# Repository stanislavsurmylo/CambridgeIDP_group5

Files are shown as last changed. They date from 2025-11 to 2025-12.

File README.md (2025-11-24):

# CambridgeIDP_group5

This repository contains our code and CAD models the Cambridge IB IDP group M205. 

# Team members 
1. Victor Liu
2. Luke Wiggins
3. Su Liu
4. Mykhailo (Misha) Lysakov
5. Arya Bhattacharya
6. Cerys Brown
7. Stanislav (Stas) Surmylo

## Team allocations
Mechanical: 
- Cerys Brown
- Luke Wiggins
- Arya Bhattacharya

Electrical:
- Victor Liu

Software: 
- Su Liu 
- Misha Lysakov
- Stas Surmylo

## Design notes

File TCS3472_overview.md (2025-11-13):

## TCS3472 Color Sensor Reader (I2C)

###
- TCS3472 RGB color and ambient light sensor
- Measures red, green, blue color values and light intensity
- I2C digital interface (3.3–5 V compatible)
- Onboard LED for illumination

### Wiring
- `SDA` ➜ GP4
- `SCL` ➜ GP5
- `VCC` ➜ 3V3 (or 5V)
- `GND` ➜ GND

### Notes
- Returns RGB tuple (red, green, blue) and light value
- I2C address: 0x29 (default)
- Readings update every 1 second (configurable)
- Requires driver: `libs/tcs3472_micropython/tcs3472.py`

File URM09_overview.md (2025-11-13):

## URM09 Analog Distance Tracker 

###
- URM09 Ultrasonic Distance Sensor (2–500 cm)
- Outputs an **analog voltage** that changes with distance
-  `distance_cm = (Vout(mV) × 520) / Vin(mV)`
- With 3.3 V supply: `distance_cm ≈ volts × 157.58`

### Wiring
- `AOUT` ➜ GP26 (ADC0)
- `VCC` ➜ 3V3
- `GND` ➜ GND

### Notes
- Analog readings can be noisy—average samples if needed
- NEED calibration!!!

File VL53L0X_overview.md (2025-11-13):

## VL53L0X ToF Distance Reader (I2C)

###
- VL53L0X Time-of-Flight sensor (30–2000 mm)
- Smart sensor with built-in laser timing and processing
- Communicates digitally over I2C (needs clock + data wires)

### Wiring
- `SDA` ➜ GP8
- `SCL` ➜ GP9
- `VCC` ➜ 3V3 (works 3.3–5 V)
- `GND` ➜ GND

### Notes
- I2C allows multiple devices on the same bus (address 0x29 default)
- Readings are 1 mm resolution, accuracy about ±3%
- Keep sensor still during init; avoid covering the aperture

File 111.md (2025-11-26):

# Loading Pipeline Overview

## Purpose
- Detect an object near the loader using the TMF8701 range sensor.
- Classify cube color with the TCS3472 only when needed to save power.
- Move the linear actuator to lift the object once distance and color checks pass.

## Hardware
- `TMF8701` time-of-flight sensor on I2C (`I2C_ID=0`, `PIN_SDA=8`, `PIN_SCL=9`).
- `TCS3472` color sensor, power-gated via `COLOR_POWER_PIN=0`.
- `Actuator` driven by direction pin `3` and PWM pin `2`.

## Configuration
- `LOADING_ZONE` selects actuator default positions (1: zone down, 2: zone up).
- Timing constants:
  - `INIT_RETRACT_TIME`: retract to bottom.
  - `ZONE_DOWN_EXTEND_TIME`: default extension for zone down.
  - `LIFT_TIME`: duration of lift once triggered.
- `REFERENCE_DISTANCE_CM` determines trigger distance (default 3 cm).

## Execution Flow
1. **Sensor Setup**  
   `setup_sensor()` initializes TMF8701 and starts distance measurement mode.
2. **Actuator Initialization**  
   `initialize_actuator()` retracts fully, then extends according to `LOADING_ZONE`.
3. **Main Loop** (`main()`):
   - Continuously reads distance via `read_distance_cm()`.
   - When distance ≤ `REFERENCE_DISTANCE_CM`, powers the TCS3472, samples light/RGB, and detects color.
   - If not previously triggered, extends actuator at `ACTUATOR_SPEED` for `LIFT_TIME` seconds, then stops.
   - Resets trigger when distance goes above `REFERENCE_DISTANCE_CM + 1`.

## Color Detection
- `detect_color()` derives normalized RGB ratios.
- Tags `RED`, `GREEN`, `BLUE`, `YELLOW`, or `DARK` / `UNKNOWN` based on thresholds.

## Operation Notes
- Loop delay is `0.2 s`, balancing responsiveness with sensor stability.
- TMF8701 measurement calls use `start()/read()/stop()` for each sample to ensure fresh data.
- Color sensor is only powered when an object is close, reducing noise and power.

## Troubleshooting
- Initialization failures raise explicit `RuntimeError` messages for quick diagnosis.
- Ensure I2C wiring matches configured pins; desktop lint warnings about `machine`/`utime` are expected on non-MicroPython hosts.

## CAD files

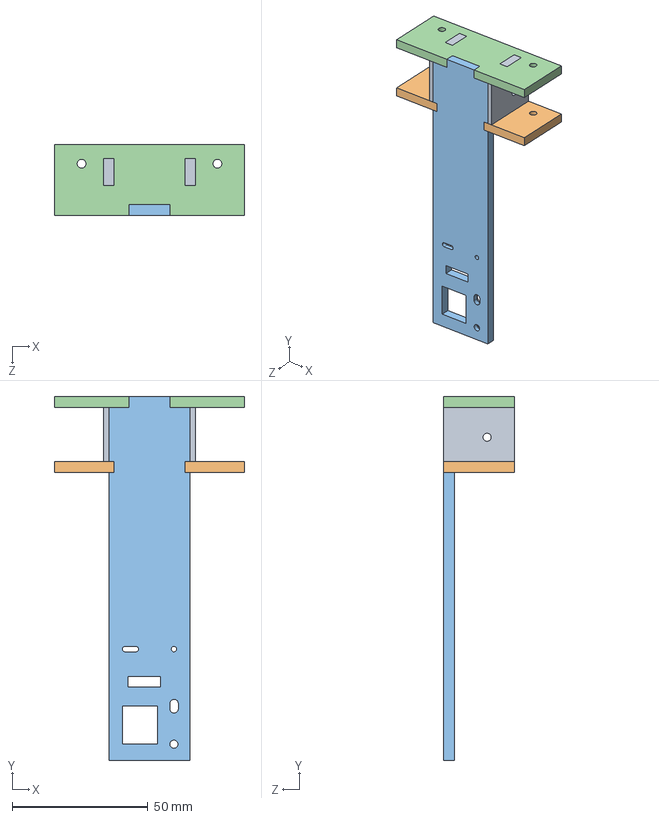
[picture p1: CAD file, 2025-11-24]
3d_models/Forklift/forklift.SLDASM
70.0 x 134.0 x 26.0 mm
forklift_baseplate
forklift_front_face
forklift_upper_notch x 2
forklift_vertical_edge x 2

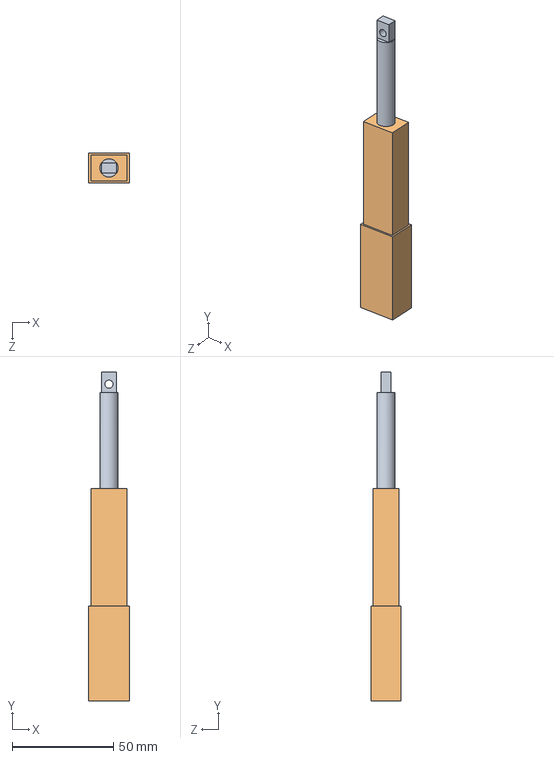
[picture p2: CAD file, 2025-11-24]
3d_models/actuator.SLDASM
20.0 x 162.4 x 15.0 mm
actuator_base
actuator_mover

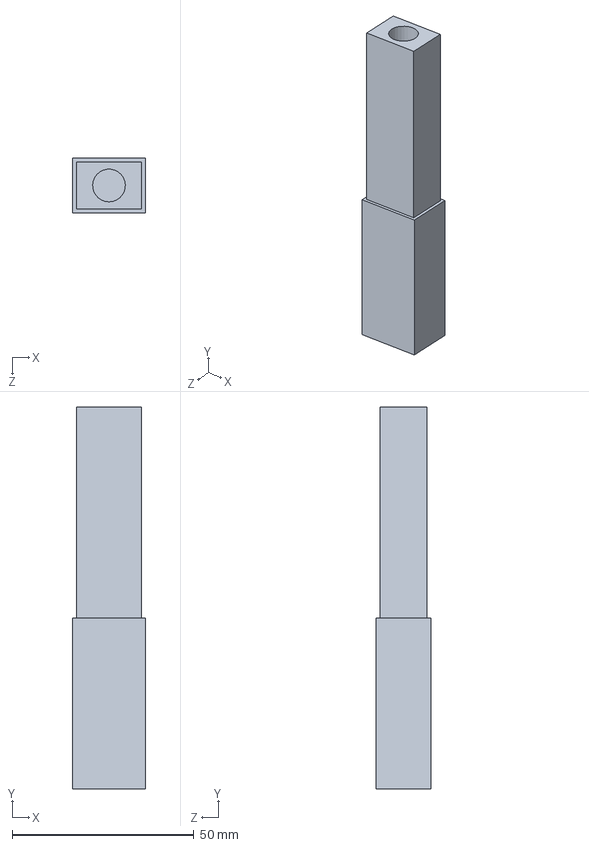
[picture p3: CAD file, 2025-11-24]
3d_models/actuator_base.SLDPRT
20.0 x 105.0 x 15.0 mm

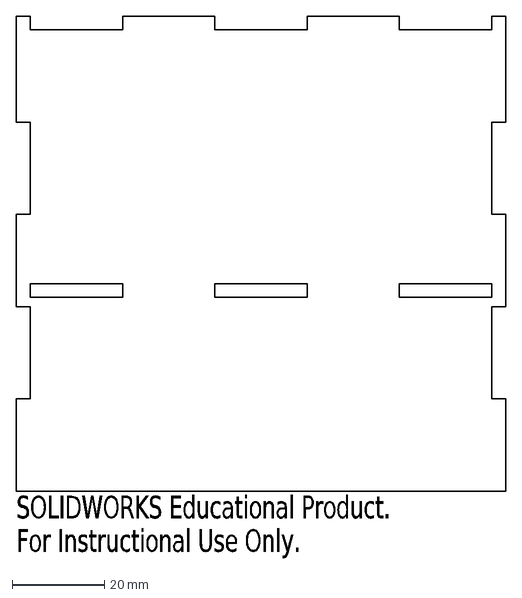
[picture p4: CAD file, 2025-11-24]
3d_models/laser cutting files/back.DXF
SOLIDWORKS Educational Product.
For Instructional Use Only.

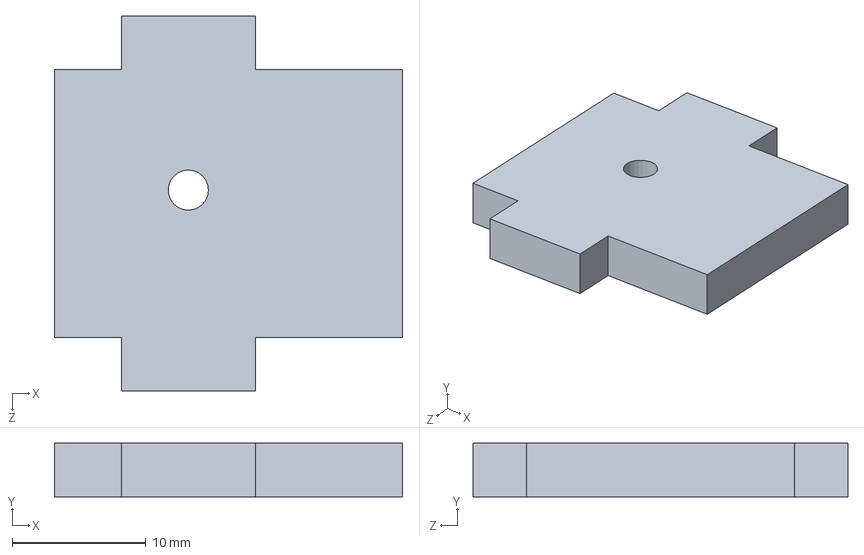
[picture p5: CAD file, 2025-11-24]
3d_models/Forklift/forklift_vertical_edge.SLDPRT
26.0 x 4.00 x 28.0 mm

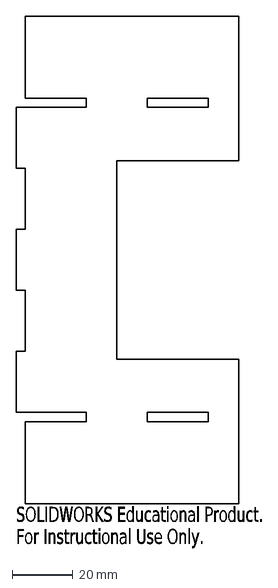
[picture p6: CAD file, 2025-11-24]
3d_models/laser cutting files/above_wheel.DXF
SOLIDWORKS Educational Product.
For Instructional Use Only.

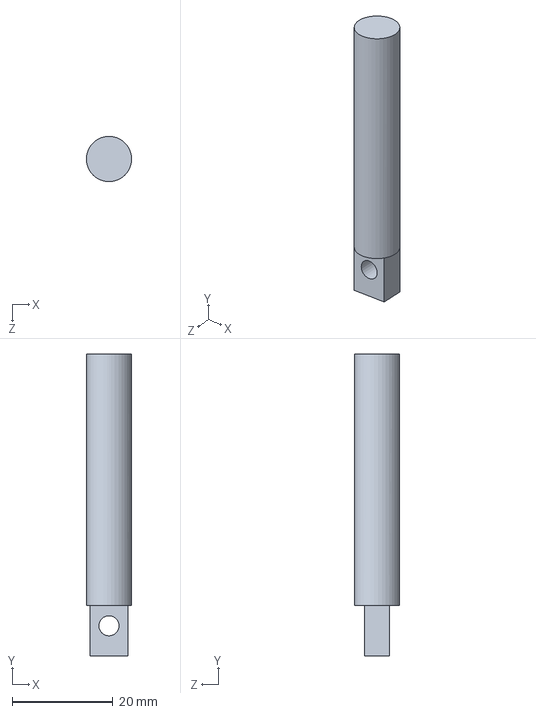
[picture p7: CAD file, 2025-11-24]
3d_models/actuator_mover.SLDPRT
8.99 x 60.0 x 9.00 mm

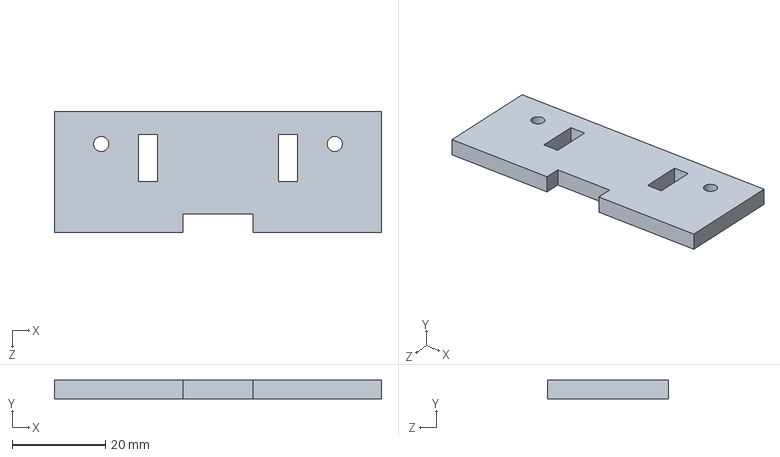
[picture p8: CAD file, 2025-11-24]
3d_models/Forklift/forklift_baseplate.SLDPRT
70.0 x 4.00 x 26.0 mm

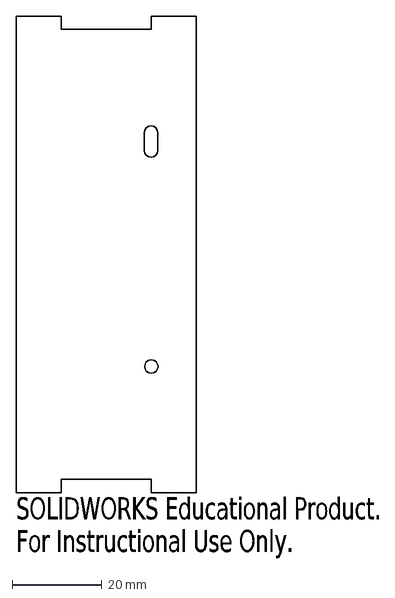
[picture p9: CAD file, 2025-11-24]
3d_models/laser cutting files/top.DXF
SOLIDWORKS Educational Product.
For Instructional Use Only.

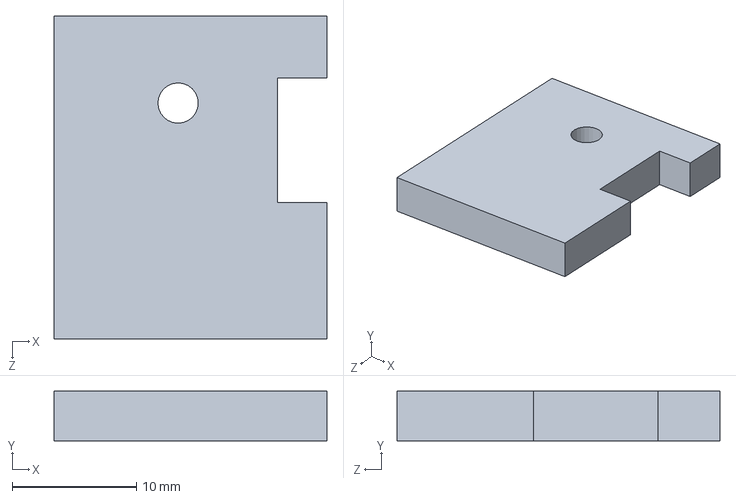
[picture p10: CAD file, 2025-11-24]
3d_models/Forklift/forklift_upper_notch.SLDPRT
22.0 x 4.00 x 26.0 mm

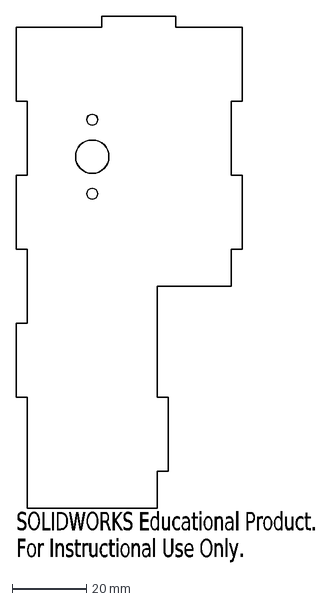
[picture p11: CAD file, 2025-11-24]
3d_models/laser cutting files/side.DXF
SOLIDWORKS Educational Product.
For Instructional Use Only.

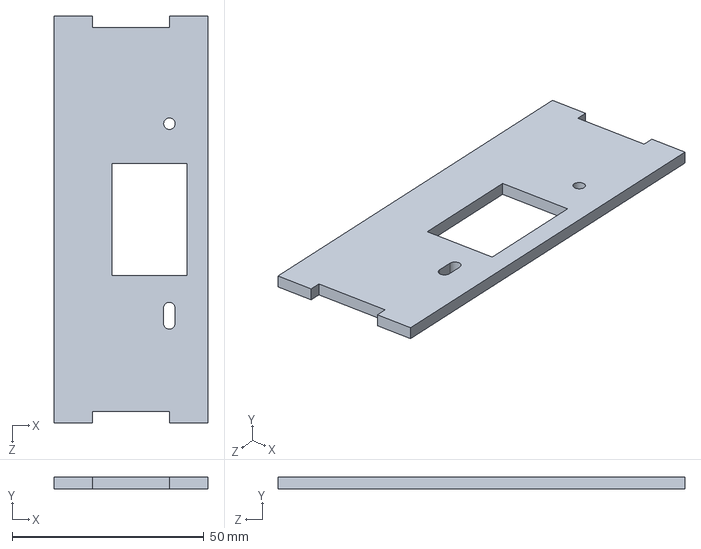
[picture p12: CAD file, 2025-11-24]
3d_models/top.SLDPRT
40.0 x 3.00 x 106.0 mm

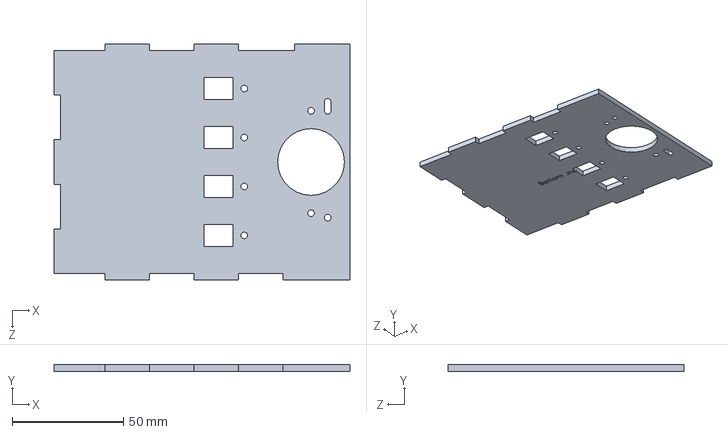
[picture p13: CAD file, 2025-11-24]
3d_models/bottom.SLDPRT
133.0 x 3.00 x 106.0 mm

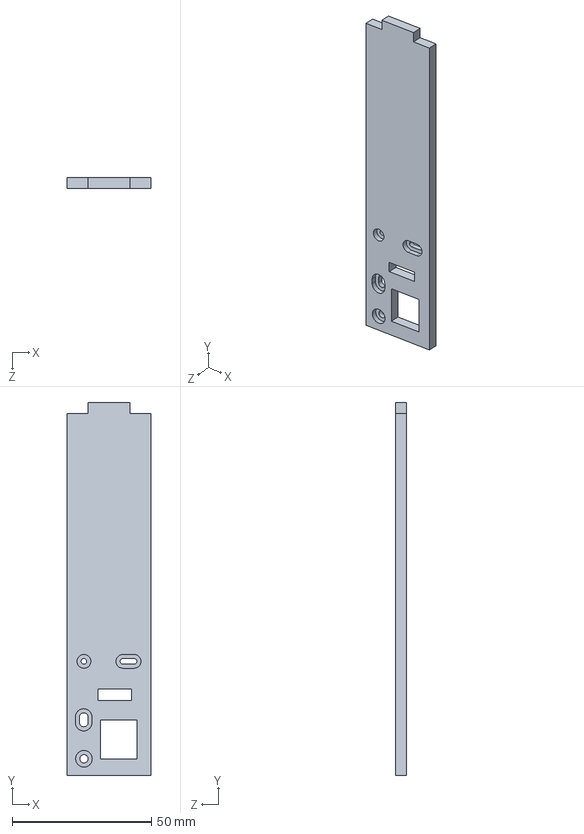
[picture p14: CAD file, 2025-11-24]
3d_models/Forklift/forklift_front_face.SLDPRT
30.0 x 134.0 x 4.00 mm

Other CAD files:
3d_models/box_assembly.SLDASM
3d_models/ballbearing_and_mount.SLDASM
3d_models/laser cutting files/bottom.DXF
3d_models/back.SLDPRT
3d_models/Forklift/forklift.SLDPRT
3d_models/Forklift/forklift.STL
3d_models/above_wheel.SLDPRT
3d_models/ballbearing mount.SLDPRT
3d_models/ballbearing.SLDPRT
3d_models/battery.SLDPRT
3d_models/pico.SLDPRT
3d_models/side.SLDPRT
3d_models/wheel.SLDPRT

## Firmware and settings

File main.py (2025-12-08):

# four_sensor_table_arc.py — 4-bit follower + debounced arc turns
import loading_pipeline_state_machine
# Core line-following and loading logic for the robot. Additive comments only;
# functional code remains unchanged.
from machine import Pin, PWM, I2C
from time import sleep_ms, ticks_ms, ticks_diff, sleep
import rp2
import map
from map import V
import vl53l0x_distance
from vl53l0x_distance import setup_sensor_vl53l0x, vl53l0x_read_distance
from libs.tmf8701 import DFRobot_TMF8701
from linear_actuator import Actuator
import loading_pipeline
from loading_pipeline import loading_pipeline_main
from loading_pipeline_state_machine import LoadingPipelineState, pipeline_step

PIN_YELLOW = 17
BUTTON_PIN = 14 
 # zone down = 1, zone up = 2

# I2C pins shared with TMF8701
I2C_ID = 0
PIN_SDA = 8
PIN_SCL = 9

# I2C pins for TCS3472
I2C_ID_TCS3472 = 1
PIN_SDA_TCS3472 = 10
PIN_SCL_TCS3472 = 11

# TCS3472 power control
COLOR_POWER_PIN = 0
COLOR_POWER_STABILIZE_MS = 200
COLOR_INTEGRATION_MS = 500
# Above constants group hardware pin definitions and timing knobs. Values tuned
# on physical hardware, so untouched for correctness.

# Actuator pins
ACTUATOR_DIR_PIN = 3
ACTUATOR_PWM_PIN = 2

# Timing constants
INIT_RETRACT_TIME = 6.0  # Retract to bottommost position
ZONE_DOWN_EXTEND_TIME = 3.0  # Extend to default position for zone_down
ZONE_UP_EXTEND_TIME = 0  # Extend to default position for zone_up
LIFT_TIME = 3.0  # Base lift time when starting loading
ACTUATOR_SPEED = 70

MIN_INIT_DISTANCE_CM = 5
ZONE_PRESET_DISTANCE_CM = 10.0 # Trigger zone preset extend
COLOR_REFERENCE_DISTANCE_CM = 5  # Trigger color sampling
LIFT_REFERENCE_DISTANCE_CM = 3  # Trigger lift phase
LOOP_DELAY = 0.2


# ----- TUNING -----
BASE  = 80    # straight speed
SPIN_BASE = 50
LOAD_BASE = 40
SEEK_COEFF = 0.5  # how aggressively to seek line
DELTA = 20*(BASE/60)    # small correction to reach 0110
HARD  = 40*(BASE/60)    # strong correction when far(turns)
TURN_OUT = 100 # arc outer wheel speed
TURN_IN  = 0 # arc inner wheel speed
DEBOUNCE = 3  # front trigger must persist N cycles
STABLE   = 1  # need N centered readings to finish a turn
MAX_TURN_MS = 10                                                 
  
COLOUR_DETECTION_DISTANCE = 50  # distance to detect color in mm
PICKUP_DISTANCE = 40.0  # distance to pick up box in mm

DT_MS = 5


RADIUS_OF_TURN = 16.5  # radius of turn in cm

    # Radius of turn = 16.5 cm
    # Angle is 90 degrees
    # turn distance is (π * 16.5) / 2 = 25.9 cm
    # Speed is 15 cm/F at power 60
    #  At power 100, speed is 25 cm/F
    # Time to turn 25.9 cm at 25 cm/F = 1.036 F



@rp2.asm_pio(set_init=rp2.PIO.OUT_LOW)
def blink_1hz():
    set(pins, 1)           # LED ON
    set(x, 31)             [6]
    label("delay_high")
    nop()                  [29]
    jmp(x_dec, "delay_high")

    set(pins, 0)           # LED OFF
    set(x, 31)             [6]
    label("delay_low")
    nop()                  [29]
    jmp(x_dec, "delay_low")

# def unload_robot():
#     go(0,0)
#     # Unloading robot to reduce weight on actuator
#     actuator = Actuator(ACTUATOR_DIR_PIN, ACTUATOR_PWM_PIN)
    
#     # Test retract
#     actuator.retract(speed=100)
#     sleep(1)
#     actuator.stop()
#     sleep(1)  # Pause so you can measure
#     print("Unloading complete")

# Global flags for button control
robot_started = False  # True after first button press (start)
emergency_stop = False  # True when paused (after robot has started)
global_actuator = None  # Global actuator reference for emergency stop

def _button_irq(pin):
    global robot_started, emergency_stop, global_actuator
    # Toggle run/pause states on button press; stop all motion when pausing.
    if not robot_started:
        robot_started = True
        emergency_stop = False
    else:
        emergency_stop = not emergency_stop
        if emergency_stop:
            mL.stop()
            mR.stop()
            # Stop actuator if it exists
            if global_actuator is not None:
                try:
                    global_actuator.stop()
                except:
                    pass

# Trigger on falling edge (button pressed to GND when using pull-up)
button = Pin(BUTTON_PIN, Pin.IN, Pin.PULL_UP)
button.irq(trigger=Pin.IRQ_FALLING, handler=_button_irq)

#vl53l0x distance sensor:
setup_sensor1 = setup_sensor_vl53l0x()

# colour sensor:
color_power = Pin(COLOR_POWER_PIN, Pin.OUT, value=0)

# Global variable to store initialized sensor (singleton pattern)
_setup_sensor2 = None

def actuator_slope_up():
    actuator = Actuator(ACTUATOR_DIR_PIN, ACTUATOR_PWM_PIN)
    actuator.extend(speed=100)
    sleep(0.1)
    actuator.stop()
    sleep(0.1)
    print("Actuator slope up complete")

def actuator_slope_down():
    actuator = Actuator(ACTUATOR_DIR_PIN, ACTUATOR_PWM_PIN)
    actuator.retract(speed=100)
    sleep(0.1)
    actuator.stop()
    sleep(0.1)
    print("Actuator slope down complete")

def setup_sensor_tmf8701():
    global _setup_sensor2
    # Return existing sensor if already initialized
    if _setup_sensor2 is not None:
        return _setup_sensor2
    
    try:
        i2c = I2C(I2C_ID, sda=Pin(PIN_SDA), scl=Pin(PIN_SCL))
        sensor = DFRobot_TMF8701(i2c)
        if sensor.begin() != 0:
            raise RuntimeError("TMF8701 initialization failed")
        if not sensor.start_measurement(sensor.eMODE_NO_CALIB, sensor.eCOMBINE):
            raise RuntimeError("TMF8701 failed to start measurement")
        print("TMF8701 distance reader ready.")
        _setup_sensor2 = sensor  # Store for reuse
        return sensor
    except OSError as e:
        print(f"I2C error in setup_sensor_tmf8701: {e}")
        raise
    except Exception as e:
        print(f"Error in setup_sensor_tmf8701: {e}")
        raise

def read_distance_mm(sensor):
    try:
        if sensor.is_data_ready():
            dist_mm = sensor.get_distance_mm()
            return dist_mm
    except Exception as e:
        # Handle I2C timeout or other communication errors
        print(f"I2C error in read_distance_mm: {e}")
        return None
    return None

# Global variables for sensor and loading state (initialized in main())
setup_sensor2 = None
loading_state = None


# ----- SENSORS (left->right). Swap sFL,sFR wires here if needed -----
S_FL = Pin(19, Pin.IN)   # front-left  (outer)
S_BL = Pin(21, Pin.IN)   # back-left   (inner)
S_BR = Pin(18, Pin.IN)   # back-right  (inner)
S_FR = Pin(20, Pin.IN)   # front-right (outer)
WHITE_LEVEL = 1
def W(x): return x == WHITE_LEVEL


# branch_route = []  path = list of vertices; route = list of 'L','R','F','B'
# branch_index = 0
current_heading = 0
current_vertex = V.START
finish_vertex = None
finish_heading = None


# ----- MOTORS -----
INVERT_LEFT  = False     # flip these until forward() drives robot forward
INVERT_RIGHT = False



class Motor:   
    def __init__(self, d, p, inv=False):
        self.dir=Pin(d,Pin.OUT); self.pwm=PWM(Pin(p)); self.pwm.freq(1000); self.inv=inv
    def fwd(self, sp): self.dir.value(0 ^ self.inv); self.pwm.duty_u16(int(65535*max(0,min(100,int(sp)))/100))
    def bwd(self, sp): self.dir.value(1 ^ self.inv); self.pwm.duty_u16(int(65535*max(0,min(100,int(sp)))/100))
    def stop(self): self.pwm.duty_u16(0)

mL = Motor(4,5, INVERT_LEFT)
mR = Motor(7,6, INVERT_RIGHT)
# Simple motor wrapper: forward/back/stop with PWM duty capping; inversion flag
# lets wiring swaps keep logical directions consistent.


def read_code():
    # return 4-bit left->right
    b3 = 1 if W(S_FL.value()) else 0
    b2 = 1 if W(S_BL.value()) else 0
    b1 = 1 if W(S_BR.value()) else 0
    b0 = 1 if W(S_FR.value()) else 0
    return (b3<<3)|(b2<<2)|(b1<<1)|b0


def go(vL, vR): mL.fwd(vL); mR.fwd(vR)
def spin_left(): mL.bwd(SPIN_BASE); mR.fwd(SPIN_BASE)
def spin_right(): mL.fwd(SPIN_BASE); mR.bwd(SPIN_BASE)
def go_back(vL, vR): mL.bwd(vL); mR.bwd(vR)

def shift_with_correction(duration_ms):
    global emergency_stop
    # Drive forward for a fixed time while line-correcting unless paused.
    t0 = ticks_ms()
    while ticks_diff(ticks_ms(), t0) < duration_ms:
        if emergency_stop:
            go(0, 0)
            break
        c = read_code()

        if centered(c):
            go(BASE, BASE)
        elif slight_left(c):          # call the function
            go(BASE - DELTA, BASE + DELTA)
        elif slight_right(c):         # call the function
            go(BASE + DELTA, BASE - DELTA)
        elif c in (0b1100, 0b1000):   # far to left
            go(BASE - HARD, BASE + HARD)
        elif c in (0b0011, 0b0001):   # far to right
            go(BASE + HARD, BASE - HARD)
        else:
            # unknown/lost -> move forward
            go(BASE, BASE)

        sleep_ms(DT_MS)

def shift_back_without_correction(duration_ms):
    global emergency_stop
    # Reverse straight for a fixed duration; avoids line correction for speed.
    t0 = ticks_ms()
    while ticks_diff(ticks_ms(), t0) < duration_ms:
        if emergency_stop:
            go(0, 0)
            break
        go_back(BASE, BASE)
        # c = read_code()

        # if centered(c):
        #     go_back(BASE, BASE)
        # elif slight_left(c):          # call the function
        #     go_back(BASE - DELTA, BASE + DELTA)
        # elif slight_right(c):         # call the function
        #     go_back(BASE + DELTA, BASE - DELTA)
        # elif c in (0b1100, 0b1000):   # far to left
        #     go_back(BASE - HARD, BASE + HARD)
        # elif c in (0b0011, 0b0001):   # far to right
        #     go_back(BASE + HARD, BASE - HARD)

        sleep_ms(DT_MS)



def arc(side):
    global current_heading
    add_branch_index = 0
    # Execute a 90/180 degree arc turn or short forward hop based on route code.
    if side=='R':
        DEGREE_OF_TURN = 90
        add_branch_index += 1
        go(TURN_OUT, TURN_IN)   # inner slower
        turn_sleep(DEGREE_OF_TURN, (TURN_OUT - TURN_IN))
        print('R')

    elif side=='L':
        DEGREE_OF_TURN = 90     
        add_branch_index += 1
        go(TURN_IN, TURN_OUT)
        turn_sleep(DEGREE_OF_TURN, (TURN_OUT - TURN_IN))
        print('L')
    
    elif side == 'B': 
        DEGREE_OF_TURN = 180
        add_branch_index += 1
        go(TURN_IN, TURN_OUT)
        turn_sleep(DEGREE_OF_TURN, (TURN_OUT - TURN_IN))
        print('B')

    elif side == 'F':
        add_branch_index += 1        # consume the 'F'
        go(BASE+10,BASE+10)
        sleep_ms(300)  # move forward length of line
        print('F')

    else:
        add_branch_index += 1        # consume the 'F'
        mL.stop(); mR.stop()
        sleep_ms(DT_MS)
        print('X(F)')
    return add_branch_index

def go_spin_left(deg):
    shift_with_correction((950//BASE)*40)  # move forward length of line
    spin(-90)



def turn_sleep(deg, speed):
    distance = (deg / 180) * 3.14 * RADIUS_OF_TURN  # distance to travel
    time_ms = (distance / (speed * 0.25)) * 1000 # time in ms
    sleep_ms(int(time_ms))
    

def spin(deg):
    # Spin in place until expected line pattern reappears or timeout reached.
    if deg > 0:
        distance = (deg / 180) * 3.14 * RADIUS_OF_TURN  # distance to travel
    else:
        distance = (-deg / 180) * 3.14 * RADIUS_OF_TURN  # distance to travel
    tick0 = ticks_ms()
    time_ms_min = (distance*0.5 / (SPIN_BASE * 0.25)) * 1000  # time in ms
    time_ms_max = (distance*0.75 / (SPIN_BASE * 0.25)) * 1000  # time in ms
    c = read_code()
    while (ticks_diff(ticks_ms(), tick0) < time_ms_min or (c != 0b0110 and c != 0b1111)) and ticks_diff(ticks_ms(), tick0) < time_ms_max:
        c = read_code()
        if c == 0b0110 or c == 0b1111:
            print("Centered during spin")
        if deg > 0:
            spin_right()
        else:
            spin_left()
    print('Spin time:', ticks_diff(ticks_ms(), tick0))

def centered(c):   return c == 0b0110
def slight_left(c):  return c == 0b0100
def slight_right(c): return c == 0b0010
def spin_back():
    if current_vertex in [V.B_DOWN_BEG, V.B_DOWN_END, V.A_UP_BEG, V.A_UP_END, V.BLUE]:
        spin(-180)
    else:
        spin(180)


def path_to_route(path):
    global finish_heading
    # Convert a vertex path to turn directives relative to current heading.
    route = []
    prev = path[0]
    curr = path[1]
    for edge in map.DIRECTED_EDGES:
        if edge.src == prev and edge.dst == curr:
            if edge.start_heading - current_heading == 1 or edge.start_heading - current_heading == -3:
                route.append('R')
            elif edge.start_heading - current_heading == -1 or edge.start_heading - current_heading == 3:
                route.append('L')
            elif edge.start_heading - current_heading == 2 or edge.start_heading - current_heading == -2:
                route.append('B')
            elif edge.start_heading - current_heading == 0:
                route.append('F')
            break
    for i in range(0, len(path)):
        if i == 0:
            continue
        prev = path[i-1]
        curr = path[i]
        if i + 1 < len(path):
            next = path[i+1]
        else:
            next = None
        # find the directed edge that matches prev -> curr
        for edge in map.DIRECTED_EDGES:
            if edge.src == prev and edge.dst == curr:
                if next is None:
                    edge0 = edge
                if edge.src in [V.B_DOWN_BEG, V.B_DOWN_END, V.A_DOWN_BEG, V.A_DOWN_END] and edge.dst in [V.B_DOWN_BEG, V.B_DOWN_END, V.A_DOWN_BEG, V.A_DOWN_END]:
                    for i in range(7):
                        route.append('F')
                elif edge.src in [V.B_UP_BEG, V.B_UP_END, V.A_UP_BEG, V.A_UP_END] and edge.dst in [V.B_UP_BEG, V.B_UP_END, V.A_UP_BEG, V.A_UP_END]:
                    for i in range(6):
                        route.append('F')
                else:
                    route.append(edge.turn)
                    break
    print(edge.src, edge.dst, edge.start_heading, edge.end_heading)
    finish_heading = edge0.end_heading  
        
    return route





def seek_and_find(LoadingBay):
    print("Seeking and finding at loading bay:", LoadingBay)
    # State machine for locating a box at a loading bay and triggering pickup.
    global current_heading
    global current_vertex
    global emergency_stop
    global loading_state
    global zone
    global number_of_bay
    global BASE
    global boxes_delivered
    BASE = 60
    loading_stage = 0
    turn_counter_on = True
    number_of_bay_on = True
    turn_counter = 0
    colour = None  # Initialize colour variable
    if boxes_delivered >= 1 or LoadingBay == V.A_DOWN_BEG:
        number_of_bay = (number_of_bay + 1) % 3
    TARGET_DISTANCE = 250  # target distance in mm 
    if LoadingBay == [V.B_DOWN_BEG]:
        TARGET_DISTANCE = 245  # target distance in mm 
    elif LoadingBay == [V.A_DOWN_BEG]:
        TARGET_DISTANCE = 255  # target distance in mm
    if LoadingBay in [V.B_DOWN_BEG, V.A_DOWN_BEG]:
        max_number_of_turns = 7
    else:
        max_number_of_turns = 6
    print("Max number of turns set to:", max_number_of_turns)
    for edge in map.DIRECTED_EDGES:
        if edge.src == LoadingBay and edge.dst in [V.B_DOWN_END, V.A_DOWN_END, V.B_UP_END, V.A_UP_END]:
            if edge.start_heading - current_heading == 2 or edge.start_heading - current_heading == -2:
                spin_back()
                current_heading = edge.end_heading
    if LoadingBay == V.B_UP_BEG:
        shift_back_without_correction((950//BASE)*40)
    c = read_code()
    while not emergency_stop and ((turn_counter < max_number_of_turns or (loading_stage != 0 and loading_stage != 4)) or (c == 0b1110 or c == 0b1111)):
        c = read_code()
        FL = (c>>3)&1;  FR = c&1
        mid = (c>>1)&0b11  # inner pair
        # If all four see white: follow the next route directive
        #print(branch_index)
        
        if (c == 0b1110 or c == 0b1111) and loading_stage == 0:
            if turn_counter_on:
                turn_counter += 1
                print("Turn counter increased to:", turn_counter)
            turn_counter_on = False
            sensor_distance1 = vl53l0x_read_distance(setup_sensor1)
            print("Distance:", sensor_distance1)
            if sensor_distance1 != None:
                if sensor_distance1 < TARGET_DISTANCE:  # long-range distance sensor needs fixing
                    loading_stage = 1
                    continue
                
                
        elif loading_stage == 0:  
            turn_counter_on = True

        # if c == 0b1110 and box_found:
        #     x += arc('L')                 # branch_index += arc() will consume this route entry
        #     sleep_ms(DT_MS)
        #     continue

        if c == 0b1110 and loading_stage == 1:
            BASE = 40
            go_spin_left(90)                 # branch_index += arc() will consume this route entry
            sleep_ms(DT_MS)
            loading_stage = 2
            tick0 = ticks_ms()

        elif loading_stage == 2:
            sensor_distance2 = read_distance_mm(setup_sensor2)
            print("Distance:", sensor_distance2)
            
            # Check if object is within pickup distance
            if sensor_distance2 != None:
                if sensor_distance2 < PICKUP_DISTANCE and sensor_distance2 > 0:
                    print("Object detected within pickup distance, moving to loading_stage 3")
                    delta_back_tick = ticks_diff(ticks_ms(), tick0) - 0.2
                    loading_stage = 3
            
            # Timeout handling: if no object detected within 2 seconds, reset
            if ticks_diff(ticks_ms(), tick0) > 2600:  # timeout after 2 seconds
                print("Timeout: No object detected within 2 seconds, resetting to stage 0")
                shift_back_without_correction((16//5.5)*((950//BASE)*40))
                spin(90)
                loading_stage = 0
                BASE = 60
            
            
        elif loading_stage == 3:
            BASE = 60  # reset speed after seeking
            # Run the loading pipeline state machine until it either
            # completes a lift or decides to reset the cycle.delta_back_tick
            # Reset the state machine for a new loading cycle (ensures clean state for next cycle)
            loading_state.reset_cycle_flags()
            go(0, 0)  # Stop motors
            sleep_ms(300)  # Give sensor time to stabilize after stage 2
            
            result = None
            while True:
                # Check emergency stop before each step

                if emergency_stop:
                    print("Emergency stop detected in loading_stage 3, breaking out")
                    if global_actuator is not None:
                        try:
                            global_actuator.stop()
                        except:
                            pass
                    break
                
                result = pipeline_step(loading_state)
                print("Loading pipeline step result:", result)

                # "waiting_sensor" and "monitoring" mean just keep polling
                if result in ("waiting_sensor", "monitoring", "init_unlocked", "actuator_initialized", "color_sampled"):
                    continue

                # Stop once the lift is done or the state machine resets
                if result in ("lift_triggered", "state_reset"):
                    break

                # Any unexpected result: break to avoid hanging
                print(f"Unexpected result: {result}, breaking out of state machine loop")
                break
                        # Get the detected color from state machine (may be None if no color detected)
            colour = loading_state.detected_color
            print("State machine detected color:", colour)
            # shift_back_without_correction((15.6//5.5)*((950//BASE)*40))
            
            c = read_code()
            while c != 0b1111:
                go_back(BASE, BASE)
                c = read_code()
            go(0, 0)
            unload_robot_shift(Actuator(ACTUATOR_DIR_PIN, ACTUATOR_PWM_PIN))
            shift_with_correction((890/BASE)*40)
            if LoadingBay == V.B_DOWN_BEG:
                spin(-90)
                turn_counter = max_number_of_turns + 1 - turn_counter  # exit after this
            else:
                spin(90)
            loading_stage = 4

        elif loading_stage == 4 and (c == 0b1110 or c == 0b1111 or c == 0b0111):
            if turn_counter_on:
                turn_counter += 1
                print("Turn counter increased to:", turn_counter)
            turn_counter_on = False
            if LoadingBay == V.A_DOWN_BEG:
                sensor_distance1 = vl53l0x_read_distance(setup_sensor1)
                print("Distance:", sensor_distance1)
                if sensor_distance1 != None:
                    if sensor_distance1 < TARGET_DISTANCE:  # long-range distance sensor needs fixing
                        if number_of_bay_on:
                            number_of_bay = (number_of_bay - 1) % 3
                            number_of_bay_on = False
                        continue
            
        elif loading_stage == 4:
            turn_counter_on = True
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

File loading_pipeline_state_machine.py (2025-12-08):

from machine import I2C, Pin
from utime import sleep, ticks_ms, ticks_diff

from libs.tcs3472 import tcs3472
from linear_actuator import Actuator
from libs.tmf8701 import DFRobot_TMF8701
# State machine for sensing distance/color and driving the linear actuator.

# Zone configuration: "zone_down" or "zone_up"
  # zone down = 1, zone up = 2

# I2C pins shared with TMF8701
I2C_ID = 0
PIN_SDA = 8
PIN_SCL = 9

# I2C pins for TCS3472
I2C_ID_TCS3472 = 1
PIN_SDA_TCS3472 = 10
PIN_SCL_TCS3472 = 11

# TCS3472 power control
COLOR_POWER_PIN = 0
COLOR_POWER_STABILIZE_MS = 2000
COLOR_INTEGRATION_MS =2500

# Actuator pins
ACTUATOR_DIR_PIN = 3
ACTUATOR_PWM_PIN = 2

# Timing constants
ACTUATOR_SPEED = 60
INIT_RETRACT_TIME = (50/(ACTUATOR_SPEED*0.66))*12  # Retract to bottommost position
INIT_EXTEND_TIME = (50/ACTUATOR_SPEED)*8.1 # Extend to default position for zone_down
ZONE_DOWN_EXTEND_TIME = 7.3 # Extend to default position for zone_down
ZONE_UP_EXTEND_TIME = 0.0  # Extend to default position for zone_up
LIFT_TIME = 3.0  # Base lift time when starting loading


MIN_INIT_DISTANCE_CM = 5
ZONE_PRESET_DISTANCE_CM = 10.0 # Trigger zone preset extend
COLOR_REFERENCE_DISTANCE_CM = 5  # Trigger color sampling
LIFT_REFERENCE_DISTANCE_CM = 3 # Trigger lift phase
LOOP_DELAY = 0.1
# Skip initial readings to avoid invalid data (0 values)
INITIAL_SKIP_COUNT = 3  # Skip first N readings
INITIAL_DELAY_MS = 100  # Wait N milliseconds before starting measurement

def get_zone_extend_time(zone):
    if zone == 'down':
        return ZONE_DOWN_EXTEND_TIME
    if zone == 'up':
        return ZONE_UP_EXTEND_TIME
    return 0.0

def initialize_actuator_bottom (actuator, zone):   
    actuator.retract(speed=ACTUATOR_SPEED*0.66)  # Maximum speed
    sleep(INIT_RETRACT_TIME)
    actuator.stop()
    sleep(0.1)
    print("Reached bottommost position")
    
def initialize_actuator_down(actuator, zone):
    print("Setting default position for zone {} (extending for {} seconds)...".format(zone, INIT_EXTEND_TIME))
    actuator.extend(speed=ACTUATOR_SPEED)
    sleep(INIT_EXTEND_TIME)
    actuator.stop()
    sleep(0.1)
    print("Actuator initialization complete. Ready for loading.\n")
1
def initialize_actuator_up(actuator, zone='down'):
    actuator.retract(speed=100)  # Maximum speed
    sleep(INIT_RETRACT_TIME)
    actuator.stop()
    sleep(0.1)
    print("Reached bottommost position")
    # Set default position based on zone
    zone_extend_time = get_zone_extend_time(zone)
    print("Setting default position for zone {} (extending for {} seconds)...".format(zone, zone_extend_time))
    actuator.extend(speed=ACTUATOR_SPEED)
    sleep(zone_extend_time)
    actuator.stop()
    sleep(0.1)
    print("Actuator initialization complete. Ready for loading.\n")

def perform_lift(actuator):
    print("Lift phase: extending actuator for {}s at speed {}.".format(LIFT_TIME, ACTUATOR_SPEED))
    actuator.extend(speed=ACTUATOR_SPEED)
    sleep(LIFT_TIME)
    actuator.stop()
    sleep(0.1)
    print("Lift phase complete.")

def setup_sensor_tmf8701():
    # Distance sensor initialization (shared with main.py when provided).
    i2c = I2C(I2C_ID, sda=Pin(PIN_SDA), scl=Pin(PIN_SCL))
    sensor = DFRobot_TMF8701(i2c)
    if sensor.begin() != 0:
        raise RuntimeError("TMF8701 initialization failed")
    if not sensor.start_measurement(sensor.eMODE_NO_CALIB, sensor.eCOMBINE):
        raise RuntimeError("TMF8701 failed to start measurement")
    print("TMF8701 distance reader ready.")
    return sensor

def setup_sensor_tcs3472():
    # Lazy-init color sensor; caller controls power separately.
    i2c_bus_tcs3472 = I2C(I2C_ID_TCS3472, sda=Pin(PIN_SDA_TCS3472), scl=Pin(PIN_SCL_TCS3472))
    sensor = tcs3472(i2c_bus_tcs3472)
    return sensor

def detect_color(rgb, light, zone):
    # Simple ratio-based classifier; thresholds tuned empirically per zone.
    if zone == 'down':
        r, g, b = rgb
        if light < 50 or (r == 0 and g == 0 and b == 0):
            return "DARK"
        total = r + g + b
        r_ratio = r / total
        g_ratio = g / total
        b_ratio = b / total
        print("Ratios - R:", r_ratio, "G:", g_ratio, "B:", b_ratio)

        if r_ratio > 0.27 and g_ratio > 0.27:
           return "YELLOW"
        if r_ratio > 0.33 and r > 80:
           return "RED"
        if g_ratio > 0.33 and g > 60:
           return "GREEN"
        if b_ratio > 0.33 and b > 80:
           return "BLUE"
        return "UNKNOWN"

    if zone == 'up':
        r, g, b = rgb
        if light < 50 or (r == 0 and g == 0 and b == 0):
            return "DARK"
        total = r + g + b
        r_ratio = r / total
        g_ratio = g / total
        b_ratio = b / total
    
        if r_ratio > 0.33 and g_ratio > 0.33:
            return "YELLOW"
        if r_ratio > 0.33 and r > 100:
            return "RED"    
        if g_ratio > 0.33 and g > 80:
            return "GREEN"
        if b_ratio > 0.33 and b > 100:
            return "BLUE"
        return "UNKNOWN"
    # Fallback classification (should rarely be used)
    if b_ratio > 0.33 and b > 80:
        return "BLUE"
    return "UNKNOWN"
    
def sample_color(power_ctrl, tcs3472_sensor=None):
    # Power on sensor, integrate, read, and power off; returns (light, rgb).
    try:
        sleep(COLOR_POWER_STABILIZE_MS / 1000)

        # Use provided sensor or create new one
        if tcs3472_sensor is None:
            sensor = setup_sensor_tcs3472()
        else:
            sensor = tcs3472_sensor
        sleep(COLOR_INTEGRATION_MS/1000)
        light = sensor.light()
        rgb = sensor.rgb()
        power_ctrl.value(0)
        sleep(LOOP_DELAY)
        return light, rgb
    except Exception as e:
        # Handle I2C timeout or other communication errors
        print(f"I2C error in sample_color: {e}")
        power_ctrl.value(0)  # Make sure to turn off power on error
        return (0, (0, 0, 0))  # Return default values

def read_distance_cm(sensor):
    # Wrapper that returns cm or None; isolates I2C errors.
    try:
        if sensor.is_data_ready():
            dist_mm = sensor.get_distance_mm()
            return dist_mm / 10.0
        return None
    except Exception as e:
        # Handle I2C timeout or other communication errors
        print(f"I2C error in read_distance_cm: {e}")
        return None
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

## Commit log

2025-11-11 added motor test
2025-11-12 Add distance tracking functionality with ADC and I2C sensors
2025-11-12 sensor test
2025-11-12 Two distance sensors and their instructions
2025-11-12 Add the color sensor TCS3472 driver and overview
2025-11-13 Resolve merge: take remote version of test_move_2.py
    [main.py, test_move_2.py]
2025-11-13 Create libs folder and add TCS3472 and VL53L0X drivers
2025-11-13 Yellow LED Blink
2025-11-14 PIO contrl of amber led blink
2025-11-14 PIO control of amber led blink
2025-11-16 main.py working, small fix in route.py for skipping turns without shifting
    [main.py, route.py]
2025-11-17 uploaded CAD files
    [above_wheel.SLDPRT, ballbearing mount.SLDPRT, ballbearing.SLDPRT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]
2025-11-20 updated and added all versions of CAD models
    [623-flanged.SLDASM, 624-flanged.SLDASM, 625-flanged.SLDASM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]
2025-11-20 removed and updated forklift files to conform to typical github file structure
    [623-flanged.SLDASM, 624-flanged.SLDASM, 625-flanged.SLDASM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]
2025-11-25 found bag for skipping loading bays
    [main.py]
2025-11-26 Update loading and unloading pipelines and button behavior
2025-11-26 Update sensor handling and pipelines
2025-11-27 Update main loading logic and actuator behaviour
2025-11-27 Save all current docs and code
2025-11-27 Update main logic, loading pipeline, and LED blink behavior
2025-11-27 Adjust main loop and actuator init logic
2025-11-30 fix+two actuator init modes
    [loading_pipeline_state_machine.py, main.py]
2025-11-30 map fix or B_UP loading bay
    [map.py]
2025-11-30 error handling when the box is pushed
    [main.py]
2025-11-30 Button test
2025-12-01 long-range sensor enabled
